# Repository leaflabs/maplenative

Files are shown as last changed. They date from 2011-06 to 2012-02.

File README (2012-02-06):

This is the repository for the LeafLabs Maple Native design. This
design was created in KiCad. In order to properly view the schematics,
and to make any changes to the design, you must add the leaf hardware
and schematics libraries, available at
    http://github.com/leaflabs/hardware-lib. 

Once you have placed the libraries in a directory of your choosing,
add them as follows:

1. In EESchema (the schematic editor), click Preferences -> Library
   (or, depending on your version of KiCad, Preferences -> Libs and
   Dir). Click Add, browse to the location of leaf.lib, open it, and
   click Save Cfg. Save your project and close.

2. In CVpcb (components to modules), click Preferences ->
   Configuration. Click the Add button above the libraries window, and
   browse to the location of leaf.mod. Save the config and close.

3. In PCBnew (PCB editor), click Preferences -> Library. If leaf.mod
   is not already present, add it, save config, and close.

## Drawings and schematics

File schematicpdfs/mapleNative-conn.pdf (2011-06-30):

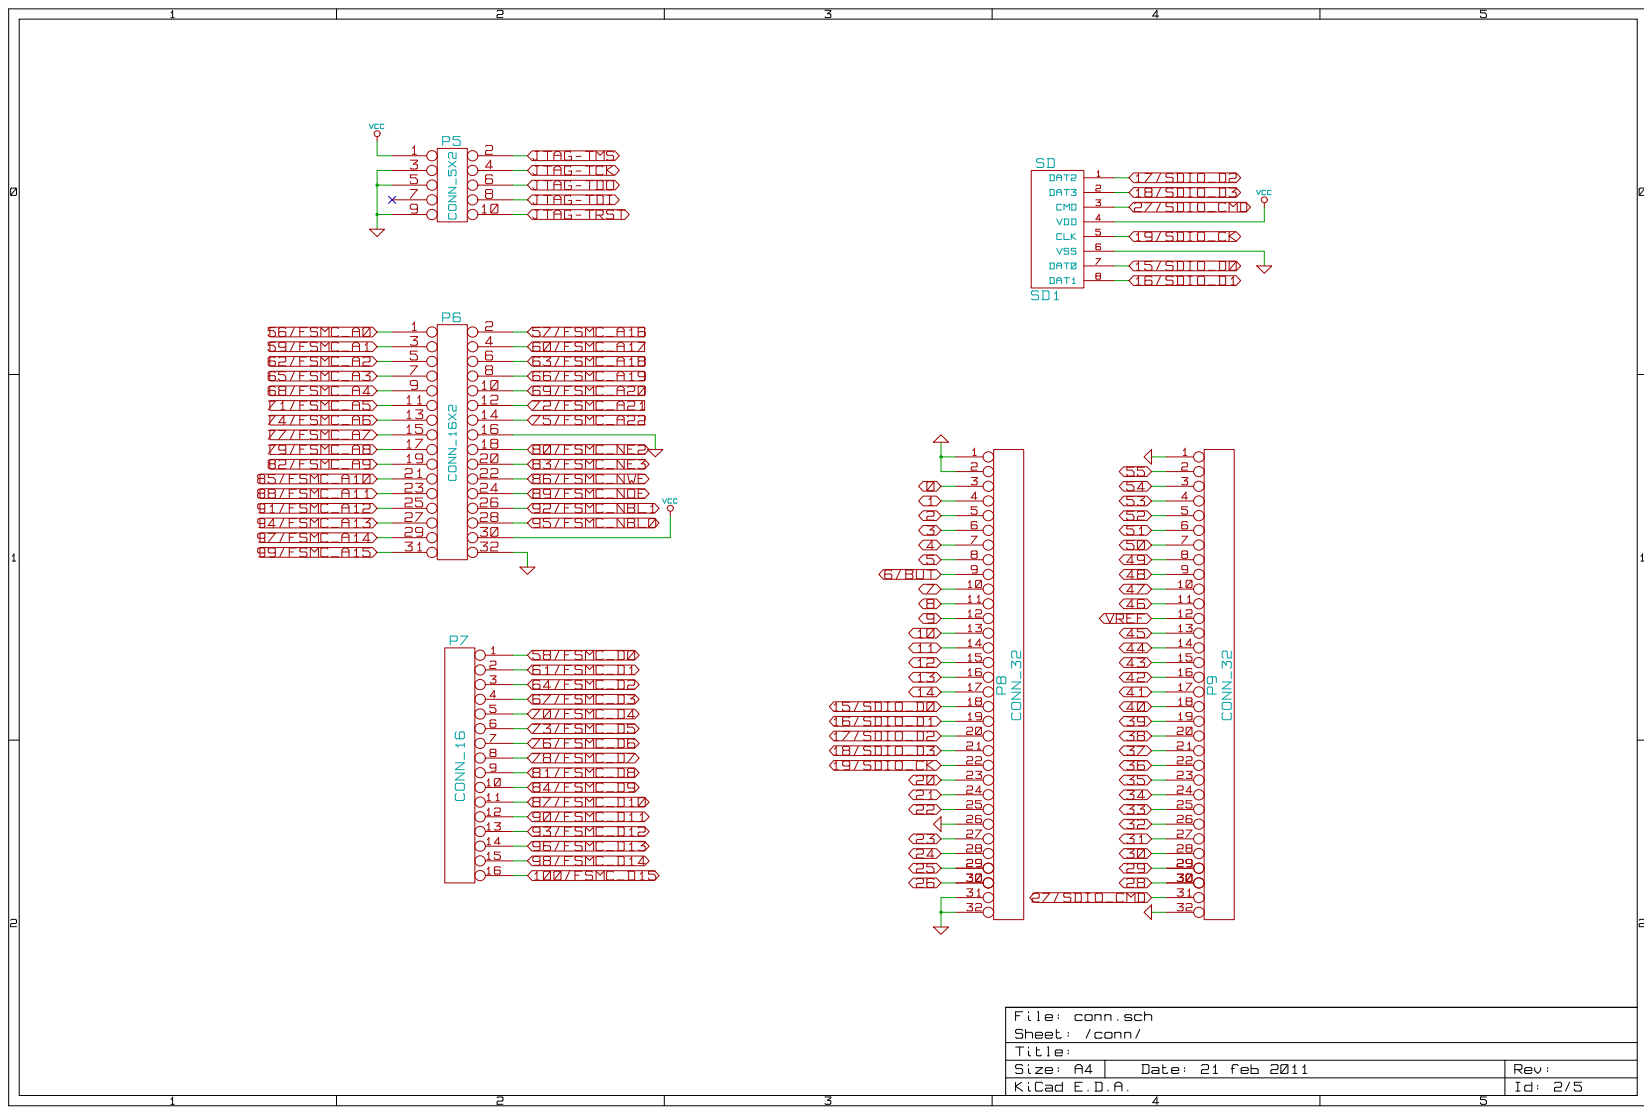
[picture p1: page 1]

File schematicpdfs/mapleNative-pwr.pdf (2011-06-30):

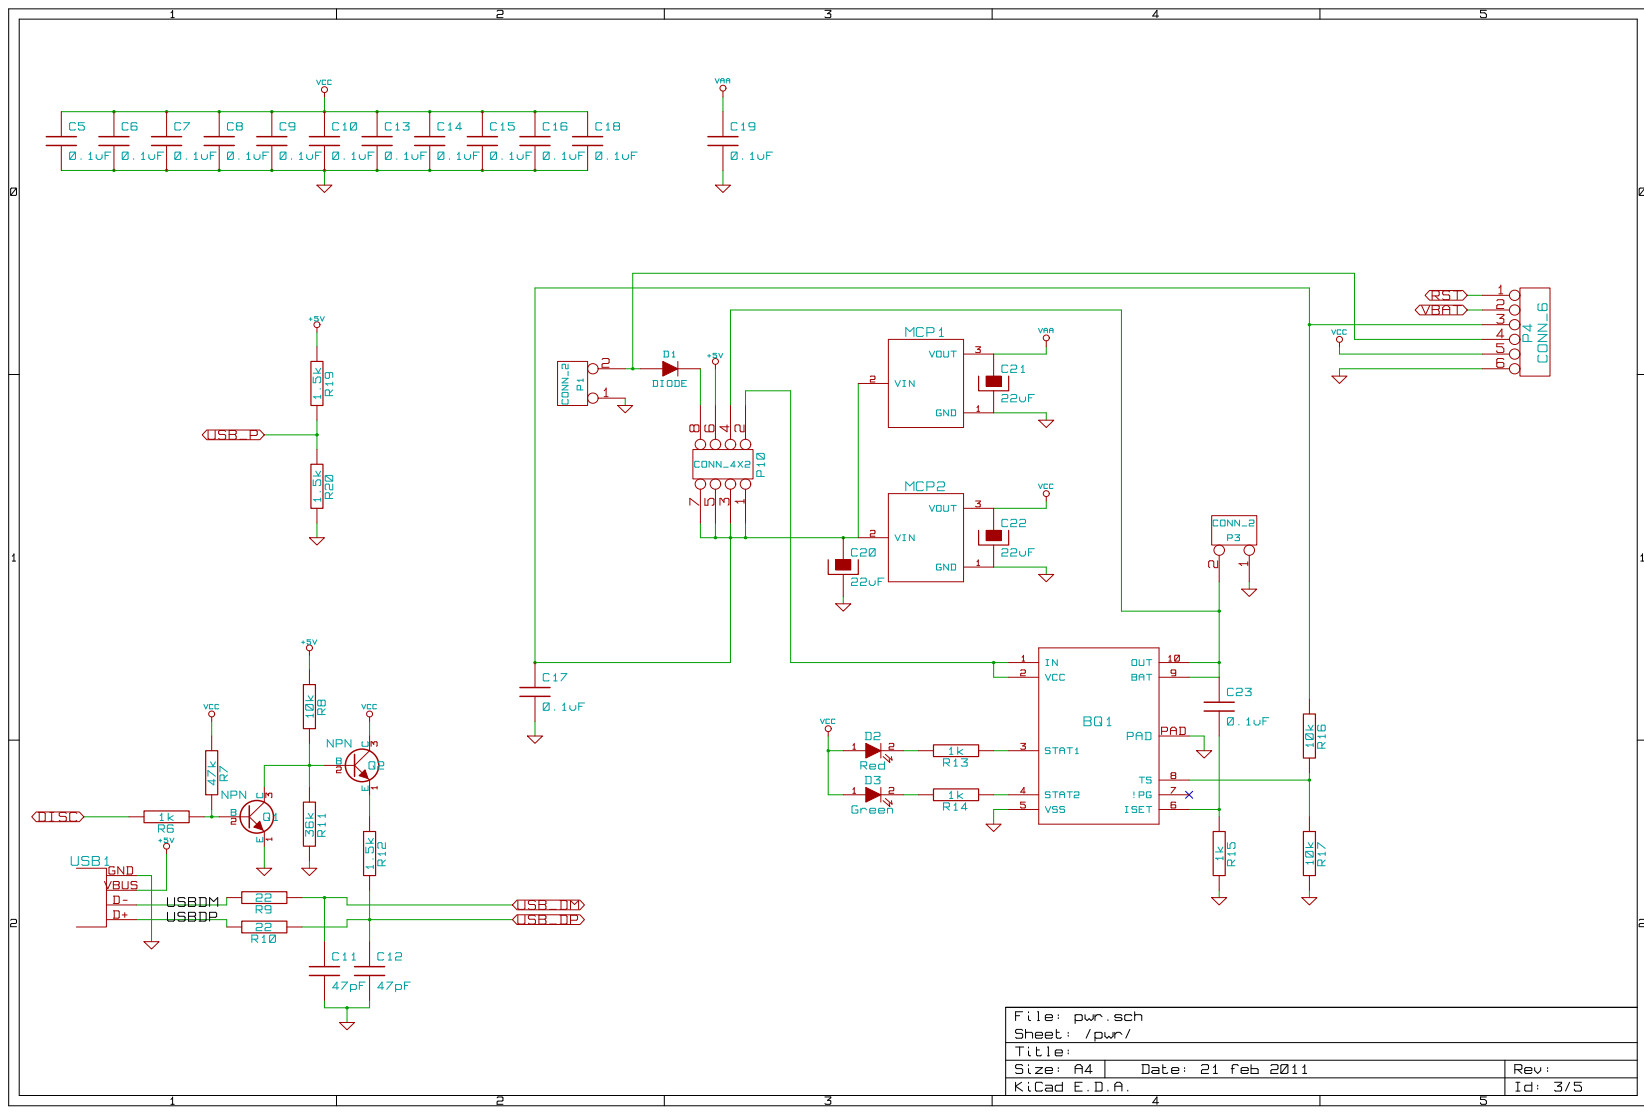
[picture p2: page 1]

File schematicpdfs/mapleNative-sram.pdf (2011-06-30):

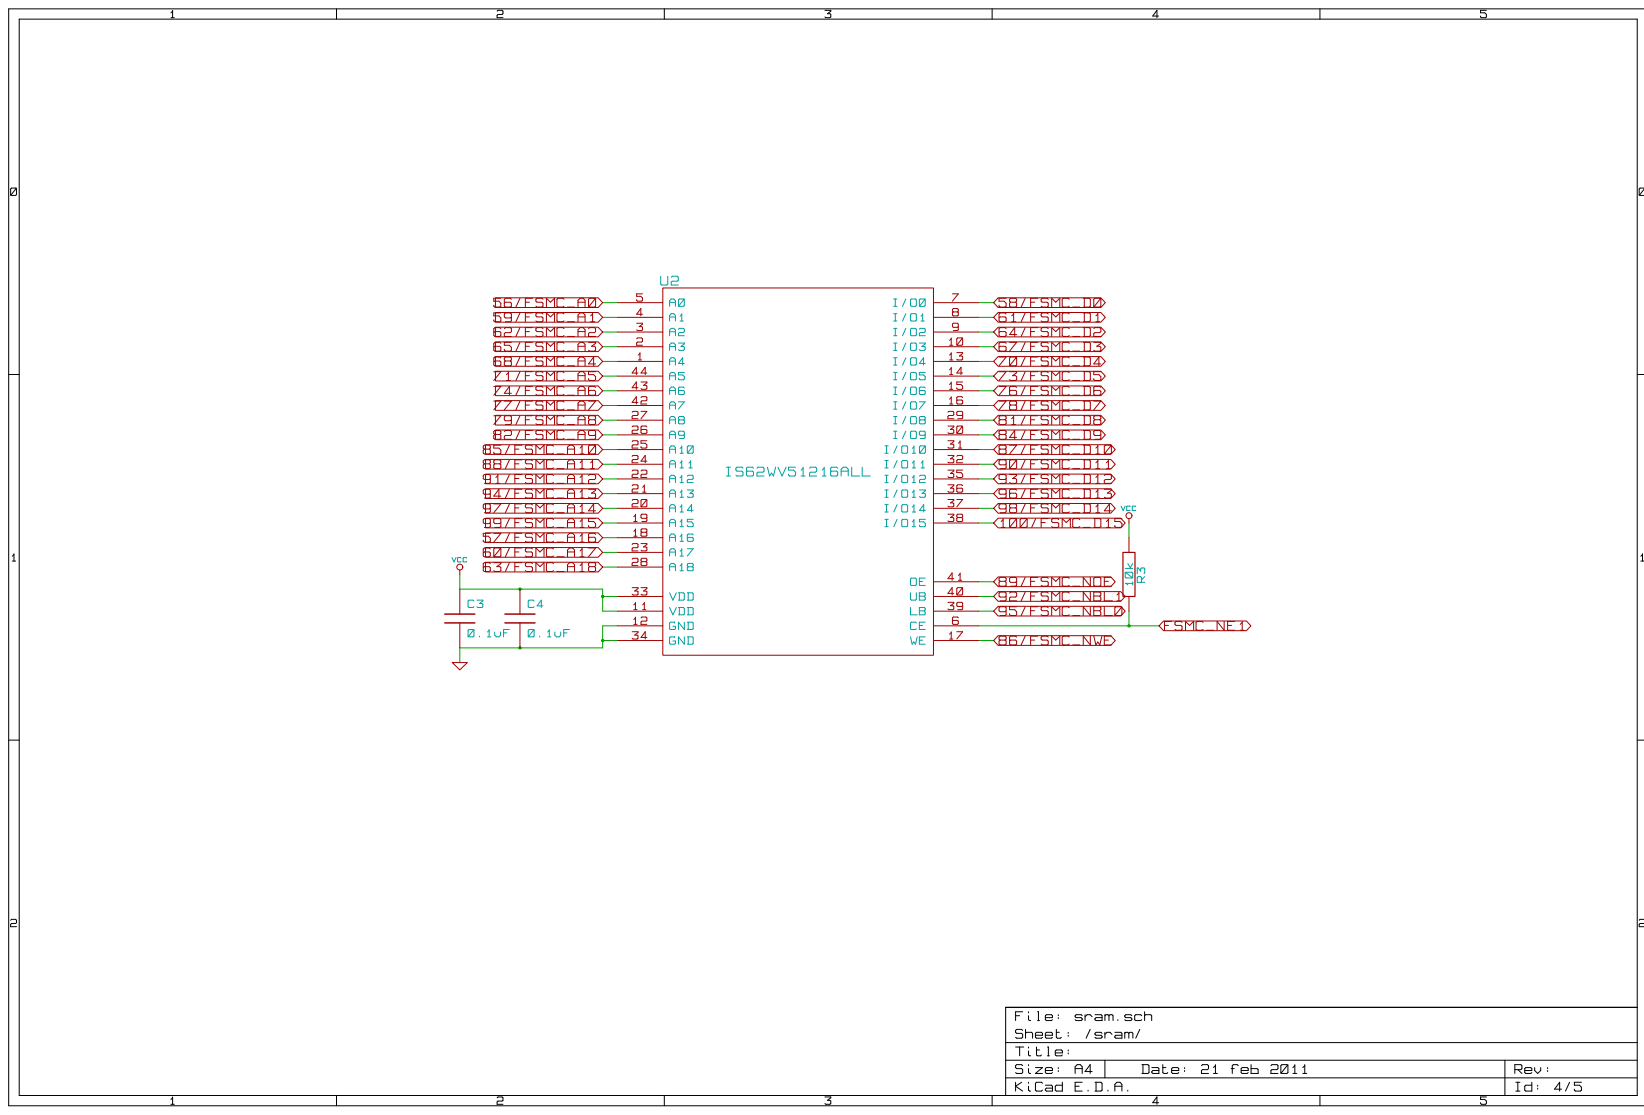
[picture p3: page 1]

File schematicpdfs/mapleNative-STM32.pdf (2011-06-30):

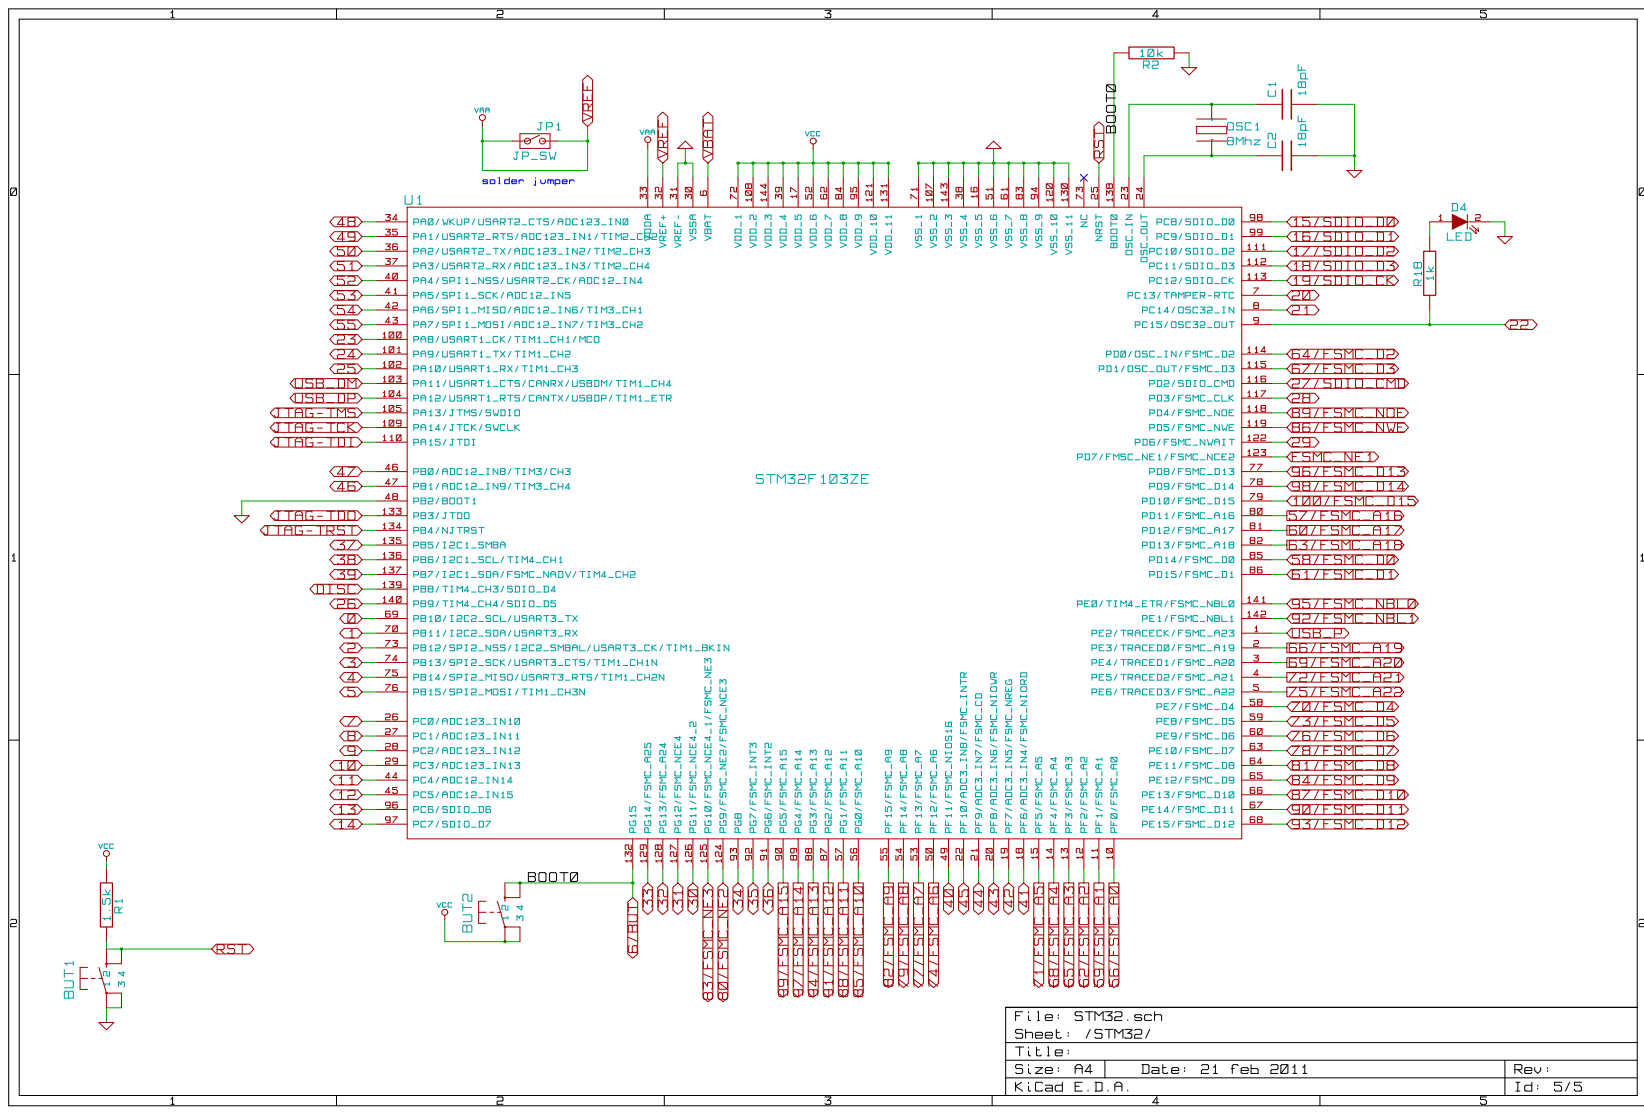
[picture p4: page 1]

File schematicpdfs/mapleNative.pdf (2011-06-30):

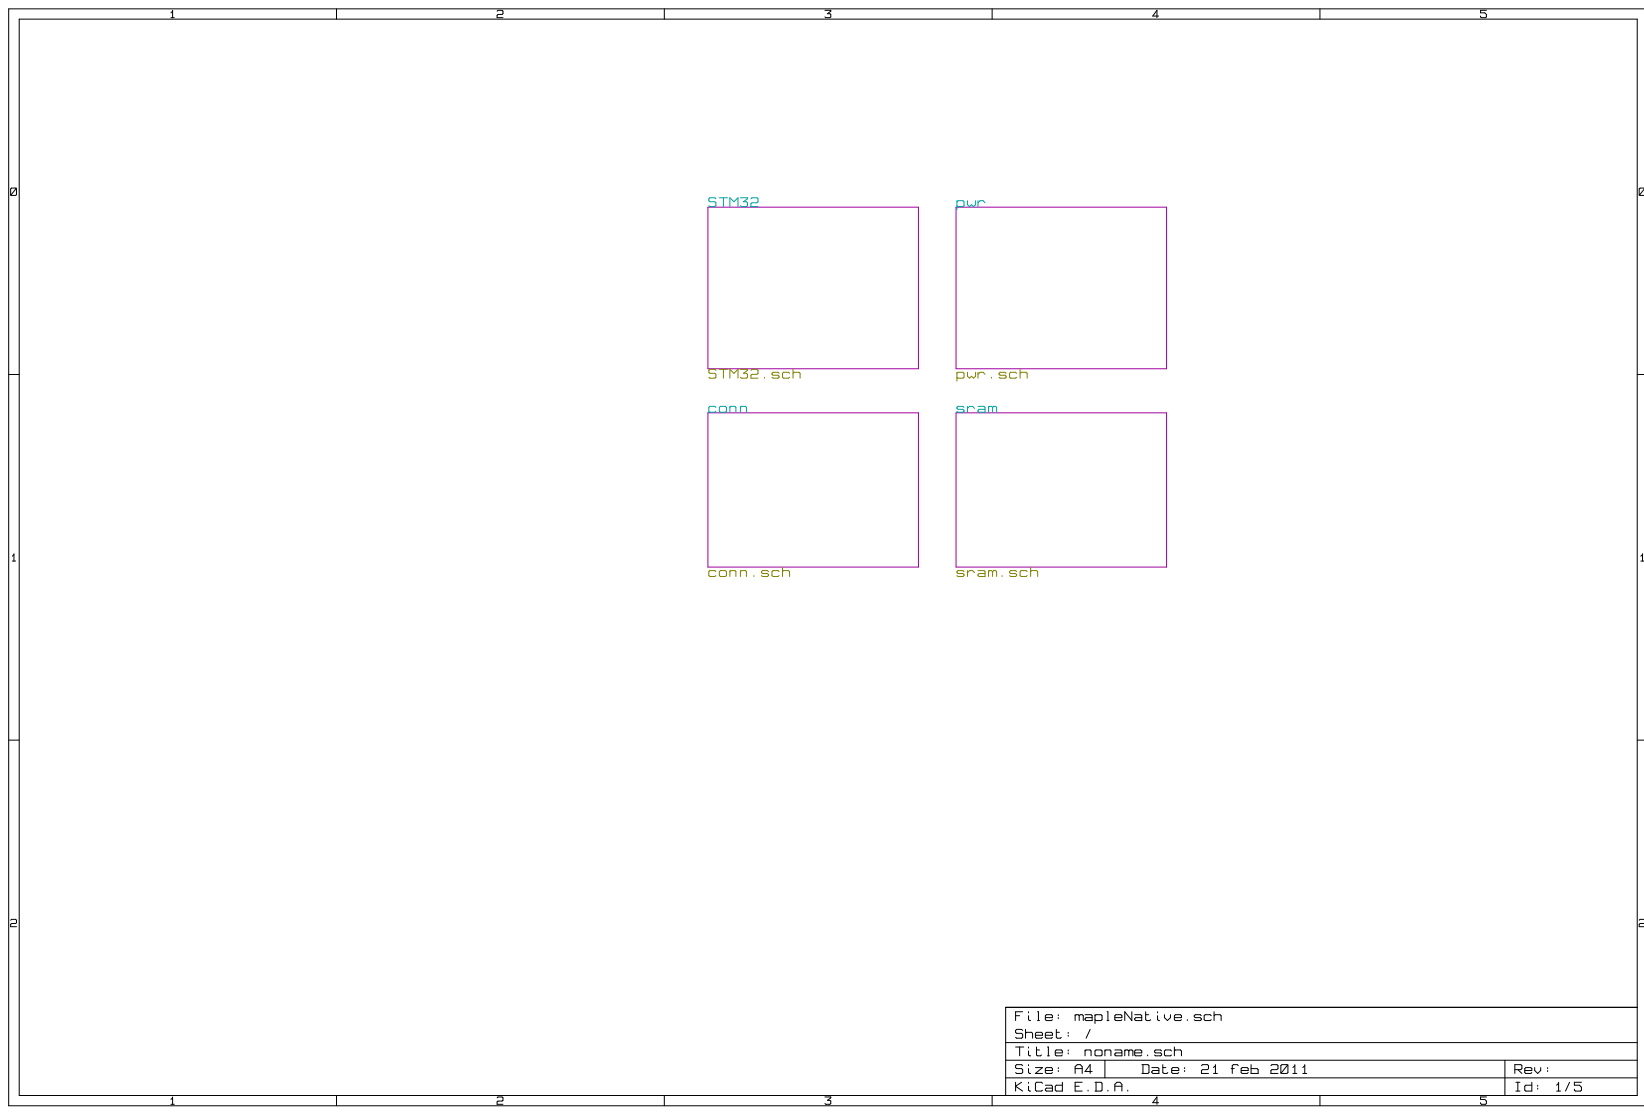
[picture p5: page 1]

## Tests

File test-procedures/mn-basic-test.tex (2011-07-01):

\documentclass[a4paper,12pt]{report}
\usepackage{graphicx}
\usepackage{url}
\begin{document}
\title{Maple Native Basic Test Procedures}
\author{LeafLabs}
\maketitle

\section*{}
\subsection*{1. Purpose of this Document}
This document provides basic setup and testing procedures for the LeafLabs Maple Native board. After following the procedures outlined in this document, basic functionality of the Maple Native board is guaranteed. The procedures in this document do not test full functionality of the Maple Native board, and additional testing is required before the board may be considered ``Quality Checked''.\\

You will need:

\begin{itemize}
\item a computer with all the required software
\item Mini-B USB cable
\item Serial-USB adapter (FTDI) with jumper wires to connect to Maple USART
\item a supply of header jumpers (2x per board)
\end{itemize}

\clearpage
\subsection*{2. Visual Inspection}

A brief visual inspection of the board should be performed to make sure there are no egregious physical errors. Some things to look out for are as follows:
\begin{itemize}
\item Is the silkscreen in focus/legible?
\item Are the buttons firmly in place? (Give them a nudge to be sure.)
\item Are there any visible shorts between pins?
\item Are there any large lumps of solder on any of the headers?
\item Is there any un-melted solder paste?
\end{itemize}

\begin{center}
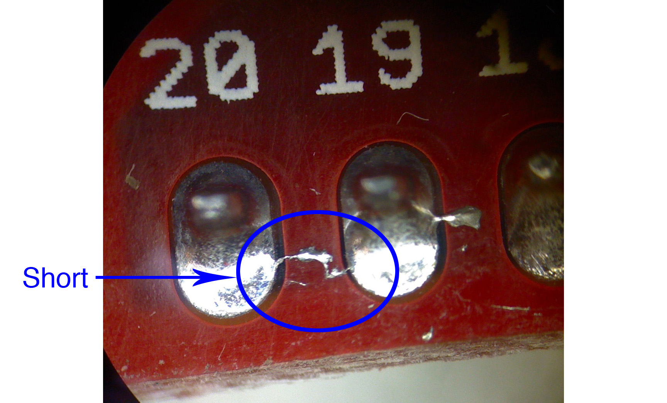
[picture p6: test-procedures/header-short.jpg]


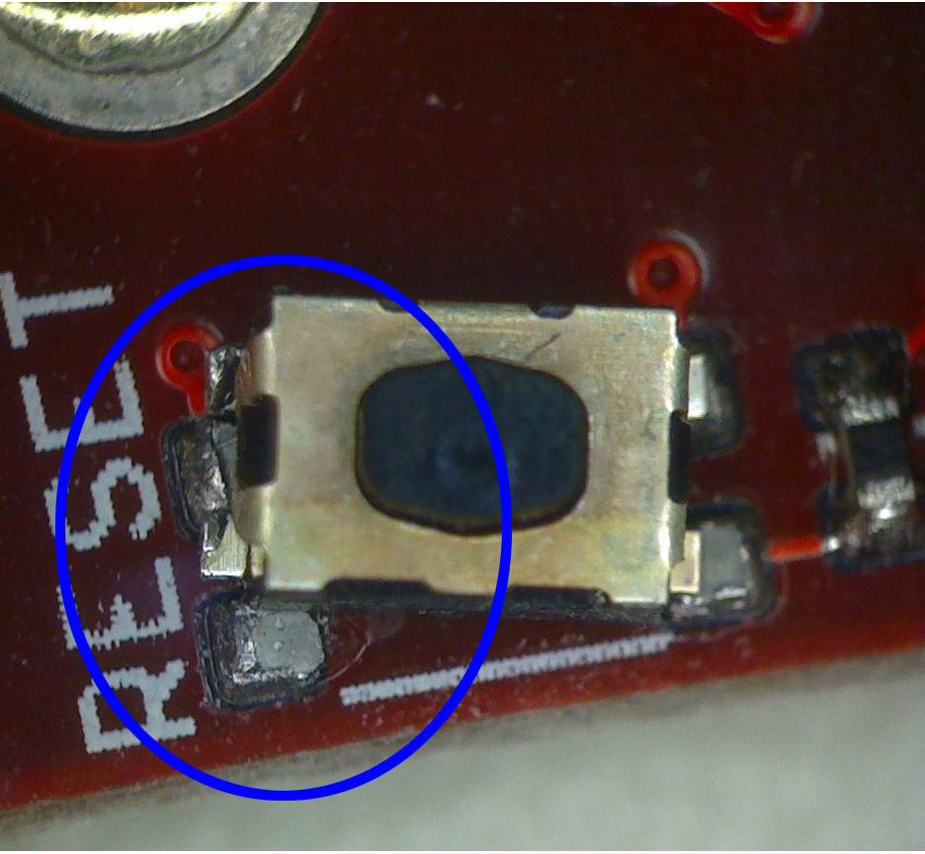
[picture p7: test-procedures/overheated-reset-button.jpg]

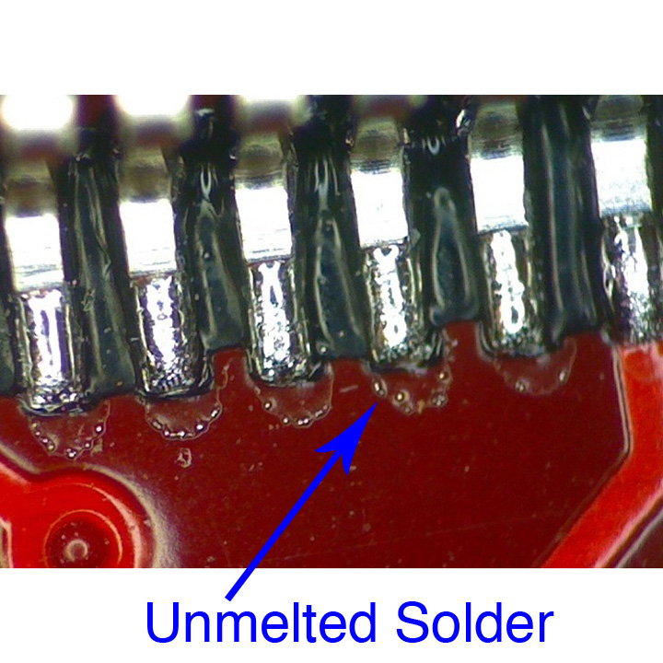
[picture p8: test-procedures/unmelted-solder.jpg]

\end{center}

%\clearpage
\subsection*{3. Attach Jumpers}

If the power select jumpers were not attached during production, they should be added at this stage. If they were attached, their proper placement should be verified. The power select jumper should be on USB and the battery charger should be half attached.

\begin{center}
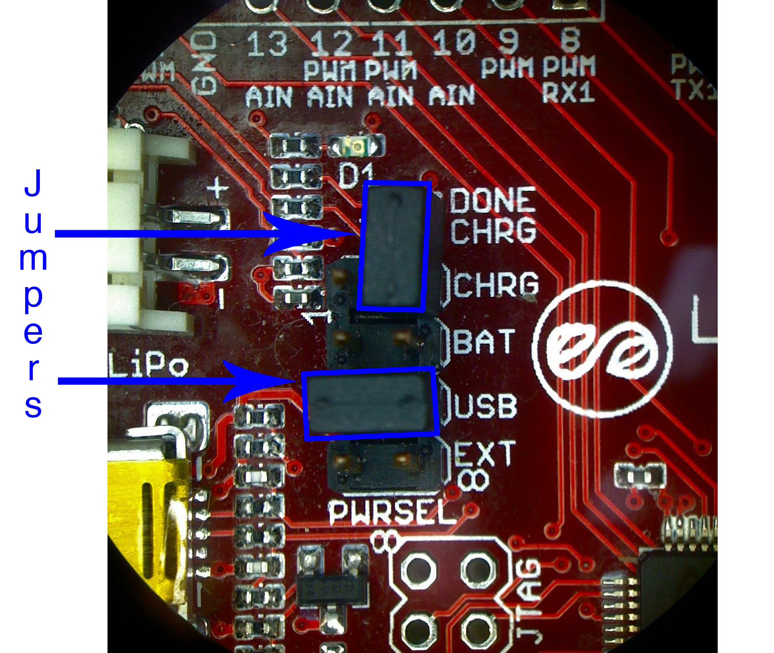
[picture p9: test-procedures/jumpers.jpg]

\end{center}

\clearpage
\subsection*{4. Flash bootloader}
The bootloader should be flashed via he hardware serial bootloader interface, as follows:

\begin{enumerate}
\item Download the stm32loader.py script from the \tt flash \rm directory of our maple-bootloader repository at \url{http://github.com/leaflabs/maple-bootloader}; this script (written by a third party) requires the PySerial library as well as a python runtime installed.
\item Get the most recent stable version of the bootloader from \url{http://static.leaflabs.com/pub/leaflabs/maple-bootloader/maple_native_boot.bin}
\item Connect both the FTDI chip and the Maple Native board to a computer via USB. Note that the Maple Native status light will not light up because there is no bootloader installed. 
\item Connect the FTDI chip to the Maple Native Serial1 USART device, which has TX1 on pin 24 and RX1 on pin 25. Be sure to connect Ground as well.
\item Ender hardware serial bootloader mode by pressing both the \tt BUT \rm and \tt RESET \rm buttons all the way down. Wait two seconds, then release \tt RESET. \rm Wait another two seconds, and release \tt BUT. \rm
\item Run the command \begin{verbatim}stm32loader.py -p /dev/ttyUSB0 -evw maple_native_boot.bin\end{verbatim} (note: this command assumes the FTDI chip is located at /dev/ttyUSB0; verify this beforehand and modify the command accordingly.) If the command runs successfully, there will be a long scroll of memory writes and verifications, then success. If the command does not run, it is possible the board did not successfully enter hardware bootloader mode. In this case, repeat steps 5 and 6 until success is achieved.
\item Press \tt RESET. \rm The blue status LED should blink perpetually.
\end{enumerate}

\clearpage
\subsection*{5. Upload test program}
To ensure basic functionality of the board, a test program must be uploaded, as follows:

\begin{enumerate}
\item Disconnect the FTDI chip from the computer and Maple Native. Leave Maple Native connected to the computer over USB.
\item Download and install the Maple IDE 0.0.10 Beta from \url{http://static.leaflabs.com/pub/leaflabs/maple-docs/0.0.10beta/maple-ide-install.html} (note: you \bf must \rm use 0.0.10 Beta; more recent versions will not work.
\item Open the Maple IDE and select Tools $\to$ Board $\to$ Maple Native (prototype) to Flash.
\item Select the appropriate serial port from Tools $\to$ Serial Port.
\item Open test program by selecting File $\to$ Examples $\to$ Digital $\to$ Blink.
\item Go to line 22 of the test program and change \begin{verbatim}int ledPin = 13;\end{verbatim} to\begin{verbatim}int ledPin = 22;\end{verbatim}
\item Click on the ``Upload'' button (second from the end) to upload the program.
\item The blue LED should now blink once per second. This, in addition to the message ``No error condition present. Done! Resetting USB switch back to runtime mode.'' from the IDE, indicates success.
\end{enumerate}

\end{document}

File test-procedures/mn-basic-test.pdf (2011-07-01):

# Maple Native Basic Test Procedures

### LeafLabs

### July 1, 2011

### 1. Purpose of this Document

This document provides basic setup and testing procedures for the LeafLabs Maple Native board. After following the procedures outlined in this document, basic functionality of the Maple Native board is guaranteed. The procedures in this document do not test full functionality of the Maple Native board, and additional testing is required before the board may be considered “Quality Checked”.

You will need:

- a computer with all the required software
- Mini-B USB cable
- Serial-USB adapter (FTDI) with jumper wires to connect to Maple USART
- a supply of header jumpers (2x per board)

1

### 2. Visual Inspection

A brief visual inspection of the board should be performed to make sure there are no egregious physical errors. Some things to look out for are as follows:

- Is the silkscreen in focus/legible?
- Are the buttons firmly in place? (Give them a nudge to be sure.)
- Are there any visible shorts between pins?
- Are there any large lumps of solder on any of the headers?
- Is there any un-melted solder paste?


2

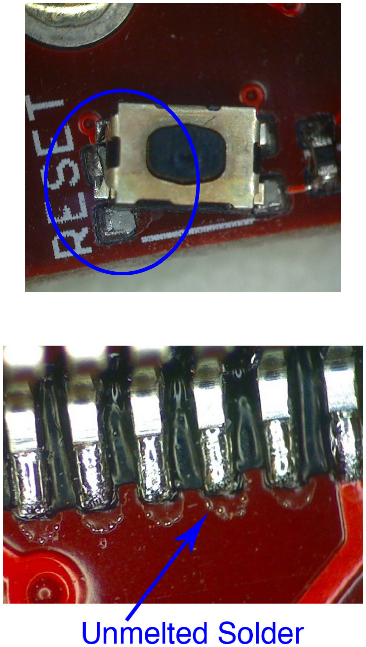
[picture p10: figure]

3

### 3. Attach Jumpers

If the power select jumpers were not attached during production, they should be added at this stage. If they were attached, their proper placement should be verified. The power select jumper should be on USB and the battery charger should be half attached.


4

### 4. Flash bootloader

The bootloader should be flashed via he hardware serial bootloader interface, as follows:

1. Download the stm32loader.py script from the flash directory of our maple-bootloader repository at http://github.com/leaflabs/maple-bootloader; this script (written by a third party) requires the PySerial library as
well as a python runtime installed.
2. Get the most recent stable version of the bootloader from http://static.leaflabs.com/pub/leaflabs/maple-bootloader/maple_native_boot.bin
3. Connect both the FTDI chip and the Maple Native board to a computer
via USB. Note that the Maple Native status light will not light up because there is no bootloader installed.
4. Connect the FTDI chip to the Maple Native Serial1 USART device, which has TX1 on pin 24 and RX1 on pin 25. Be sure to connect Ground as well.
5. Ender hardware serial bootloader mode by pressing both the BUT and RESET buttons all the way down. Wait two seconds, then release RESET. Wait another two seconds, and release BUT.
6. Run the command

stm32loader.py -p /dev/ttyUSB0 -evw maple_native_boot.bin

(note: this command assumes the FTDI chip is located at /dev/ttyUSB0; verify this beforehand and modify the command accordingly.) If the command runs successfully, there will be a long scroll of memory writes and verifications, then success. If the command does not run, it is possible the board did not successfully enter hardware bootloader mode. In this case, repeat steps 5 and 6 until success is achieved.

7. Press RESET. The blue status LED should blink perpetually.

5

### 5. Upload test program

To ensure basic functionality of the board, a test program must be uploaded, as follows:

1. Disconnect the FTDI chip from the computer and Maple Native. Leave Maple Native connected to the computer over USB.
2. Download and install the Maple IDE 0.0.10 Beta from http://static.leaflabs.com/pub/leaflabs/maple-docs/0.0.10beta/maple-ide-install. html (note: you must use 0.0.10 Beta; more recent versions will not
work.
3. Open the Maple IDE and select Tools → Board → Maple Native (prototype) to Flash.
4. Select the appropriate serial port from Tools → Serial Port.
5. Open test program by selecting File → Examples → Digital → Blink.
6. Go to line 22 of the test program and change

int ledPin = 13;

to

int ledPin = 22;

7. Click on the “Upload” button (second from the end) to upload the program.
8. The blue LED should now blink once per second. This, in addition to the message “No error condition present. Done! Resetting USB switch back to runtime mode.” from the IDE, indicates success.

6

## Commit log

2010-02-18 Initial commit.
    [mapleNative-v1.sch]
2010-02-25 Initial commit of kicad project
    [STM32.sch, bat.sch, mapleNative.sch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]
2010-03-02 sram added
    [sram.sch]
2010-03-02 ZE update
    [STM32.sch, bat.sch, mapleNative.sch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]
2010-03-02 Added ZE
    [STM32b.sch]
2010-03-05 Added connectors
    [STM32.sch, bat.sch, mapleNative.sch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]
2010-03-11 Initial netlist and brd commit
    [STM32.sch, mapleNative.brd, mapleNative.sch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]
2010-03-16 Beginning power routing
    [STM32.sch, mapleNative.brd, mapleNative.sch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]
2010-03-26 Board modifications
    [STM32.sch, mapleNative.brd]
2010-03-26 add erc, conn, pwr files
    [conn.sch, pwr.sch]
2010-03-26 Removed duplicate file
    [STM32b.sch]
2010-03-26 More removing duplicate files
    [mapleNative-v1.sch]
2010-04-02 Kicad library add
    [STM32.sch]
2010-04-20 =Merging branch
    [STM32.sch, conn.sch, mapleNative.brd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]
2010-04-20 =Added gerbers
    [mapleNative.drl]
2010-06-04 =Moved around labels for ease of assembly
    [mapleNative.brd]
2010-06-08 =Fixed button footprints, routing
    [mapleNative.brd]
2010-06-10 =Bypass cap embiggening
    [mapleNative.brd]
2010-06-10 =Added mounting holes
    [mapleNative.brd, pwr.sch]
2010-06-14 Lib add
    [mapleNative.brd]
2010-06-14 =BQ ground pad fix attempt
    [mapleNative.brd]
2010-06-16 =Added images of schematics
2010-06-30 =Yanked out traces
    [mapleNative.brd]
2010-07-07 =Ripped up traces, fixed USB drill holes
    [mapleNative.brd]
2010-07-27 =Started fsmc bus
    [STM32.sch, conn.sch, mapleNative.brd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]
2010-08-02 =fixing trace spacing
    [conn.sch, mapleNative.brd]
2010-08-02 =spacing fixed
    [mapleNative.brd]
2010-08-03 =Started routing headers
    [STM32.sch, conn.sch, mapleNative.brd]
2010-08-09 FSMC routng
    [mapleNative.brd]
2010-08-12 FSMC routing
    [mapleNative.brd]
2010-08-12 ADC line switch
    [STM32.sch, conn.sch, mapleNative.brd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]
2010-08-12 About to perform surgery
    [mapleNative.brd]
2010-08-13 Mid surgery
    [mapleNative.brd]
2010-08-25 All IO routed
    [mapleNative.brd]
2010-08-25 Actually All IO routed
    [mapleNative.brd]
2010-08-25 Started power, jtag routing
    [mapleNative.brd]
2010-08-27 New power configuration in sch
    [STM32.sch, conn.sch, mapleNative.sch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]
2010-08-30 Routing basically finished; added vaa zone
    [STM32.sch, conn.sch, mapleNative.brd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]
2010-09-01 Zones drawn
    [mapleNative.brd]
2010-09-01 Via drill sizes fixed
    [mapleNative.brd]
2010-09-01 DRC passed; ready for review
    [mapleNative.brd]
2010-09-01 added the gerbers zip
2010-12-17 Fixed USB line, passes drc
    [STM32.sch, conn.sch, mapleNative.brd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]
2011-01-03 Started silkscreening
    [mapleNative.brd]
2011-01-03 Mounting holes
    [mapleNative.brd]
2011-01-03 Front main headers silk screening done
    [mapleNative.brd]
2011-01-04 Silkscreening finished
    [mapleNative.brd]
2011-01-04 Changed analog power plane
    [mapleNative.brd]
2011-01-04 Changed gnd plane, refilled zone
    [mapleNative.brd]
2011-01-05 Silkscreening touchups
    [mapleNative.brd]
2011-01-05 Added gerbers, ready to submit
    [mapleNative.drl]
2011-01-06 Removed extraneous libraries
    [STM32.sch, conn.sch, mapleNative.sch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]
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2011-02-01 Changed pin labels
    [STM32.sch, conn.sch, mapleNative.sch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]
2011-02-01 Added schematic post script files
2011-02-02 Pin mapping update, fixed to remove grounds
    [STM32.sch, conn.sch, pwr.sch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]
2011-02-02 One more labeling fix
    [STM32.sch]
2011-02-03 Added FSMC pin numberings
    [STM32.sch, conn.sch]
2011-02-08 Breaking resets apart
    [STM32.sch]
2011-02-08 Part 1 of broken pin naming fix; disconnected reset lines
    [STM32.sch, conn.sch, pwr.sch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]
2011-02-08 Header fixup for reset breakout via new script, support/fix_nums.py.
    [STM32.sch, conn.sch]
2011-02-09 SRAM pin nums fixed, breaking out RST, VBAT, VOUT
    [STM32.sch, pwr.sch, sram.sch]
2011-02-09 Minor fixes
    [STM32.sch, conn.sch, mapleNative.sch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]
2011-02-11 5/6 of 6 pin header routed; about to switch out JTAG connector.
    [STM32.sch, conn.sch, mapleNative.sch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]
2011-02-11 New JTAG header added, routed.
    [STM32.sch, conn.sch, mapleNative.sch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]
2011-02-12 Cleaned up JTAG and power routing a little.
2011-02-13 Added solder jumper bridge for VREF/VAA
    [STM32.sch, conn.sch, pwr.sch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]
2011-02-14 Re-routed some AINs for better grouping.
    [STM32.sch, conn.sch]
2011-02-14 Moved buttons slightly.
    [STM32.sch, conn.sch]
2011-02-14 Starting silkscreen changes; discovered odd error in pin labeling.
    [STM32.sch, conn.sch, pwr.sch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]
2011-02-14 Silkscreen numbers fixed
    [STM32.sch, conn.sch]
2011-02-15 Silkscreen fixes.
2011-02-21 Switched out power diodes back to jumper scheme.
    [STM32.sch, conn.sch, mapleNative.sch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]
2011-02-21 Minor component value changes; minor silkscreen additions.
    [STM32.sch, pwr.sch]
2011-05-27 Updated schematic pdfs
    [STM32.sch, conn.sch, mapleNative.sch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]
2011-06-02 Add schematic PDFs (not PostScript).
2011-06-30 Added test procedures
    [mapleNative.drl]
2012-02-04 Added some missing 3d models. SRAM chip, batt. conn., batt. charger, USB
2012-02-06 Switched out header 3d models. Still not correct shapes, but slightly closer.
2012-02-06 Fixed drill size of P6 pin 1. changed from .032in to .04 in.
2012-02-16 Fixed connector 3d shapes.
2012-02-29 Schematic cosmetic fixes.
    [STM32.sch, conn.sch, mapleNative.sch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]
2012-03-01 Schematic updated for F4.
    [STM32.sch, conn.sch, mapleNative.sch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]
2012-03-01 Layout updated for F4
    [STM32.sch, conn.sch, mapleNative.brd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]
2012-03-01 Fixed pin 73 error.
    [STM32.sch, conn.sch, mapleNative.brd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]
2012-03-09 Added LTC3566 to schematic.
    [STM32.sch, conn.sch, mapleNative.sch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]
2012-03-12 Tore out old power schematics.
    [STM32.sch, conn.sch, mapleNative.sch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]
2012-03-12 Updated netlist for new power chip.
2012-03-12 Fixed diode footprint in netlist.
2012-03-13 New power components added. About to reroute things.
    [STM32.sch, conn.sch, mapleNative.brd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]
2012-03-13 Organized power components. Grouped power cmps on layout, unrouted.
    [mapleNative.brd]
2012-03-14 Partial PMIC routing.
    [mapleNative.brd]
2012-03-14 All routed except VAA.
    [STM32.sch, conn.sch, mapleNative.brd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]
2012-03-14 Re-added linear analog reg.
    [STM32.sch, conn.sch, mapleNative.brd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]
2012-03-15 All routed.
    [mapleNative.brd]
2012-03-15 Fixed LDO3V3 line; passes DRC.;
    [STM32.sch, conn.sch, mapleNative.brd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]
2012-03-15 Fixed LR input.
    [STM32.sch, conn.sch, mapleNative.brd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]
2012-03-19 Fixed logo silkscreen.
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2012-03-19 Adding Digikey P/Ns (first pass).
    [STM32.sch, conn.sch, mapleNative.sch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]
2012-03-19 Added Digikey P/Ns (second pass).
    [STM32.sch, conn.sch, mapleNative.sch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]
2012-03-20 Switched C17 to 0805 foot.
    [STM32.sch, conn.sch, mapleNative.sch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]
2012-03-20 Clean up, cosmetics.
    [STM32.sch, conn.sch, mapleNative.csv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]
